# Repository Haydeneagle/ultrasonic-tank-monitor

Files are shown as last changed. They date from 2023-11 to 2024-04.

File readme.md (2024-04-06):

# Ultrasonic Tank Monitor using ESP32-C3

## Overview

This project is a wireless water tank monitoring solution, based on the ESP32-C3 microcontroller. 

To measure the water level, the AJ-SR04M waterproof ultrasonic sensor is used, measuring the height of the water level. This measured height value combined with the tank diameter and height of the sensor above the full water mark allows for the volume of the tank to be calculated.

Currently, the data is transmitted over Wi-Fi using the MQTT protocol to communicate with a Mosquitto broker linked to Home Assistant, allowing for the data to be easily visualized and used in home automations. In the near future I will likely replace Wi-Fi with LoRa however currently I do not have a gateway, so provided Wi-Fi signal is adequate, it works well.

A custom PCB has been created to interface the ESP32-C3 with a number of ports, while also optimizing for low power usage in deep sleep with a 70uA quiescent current and 30+ day battery life. The board is powered by a single Li-ion 4.2V 18650 cell and supports charging by both 5V USB, and via the solar input.

|Ready for installation|Installed|
|:-:|:-:|
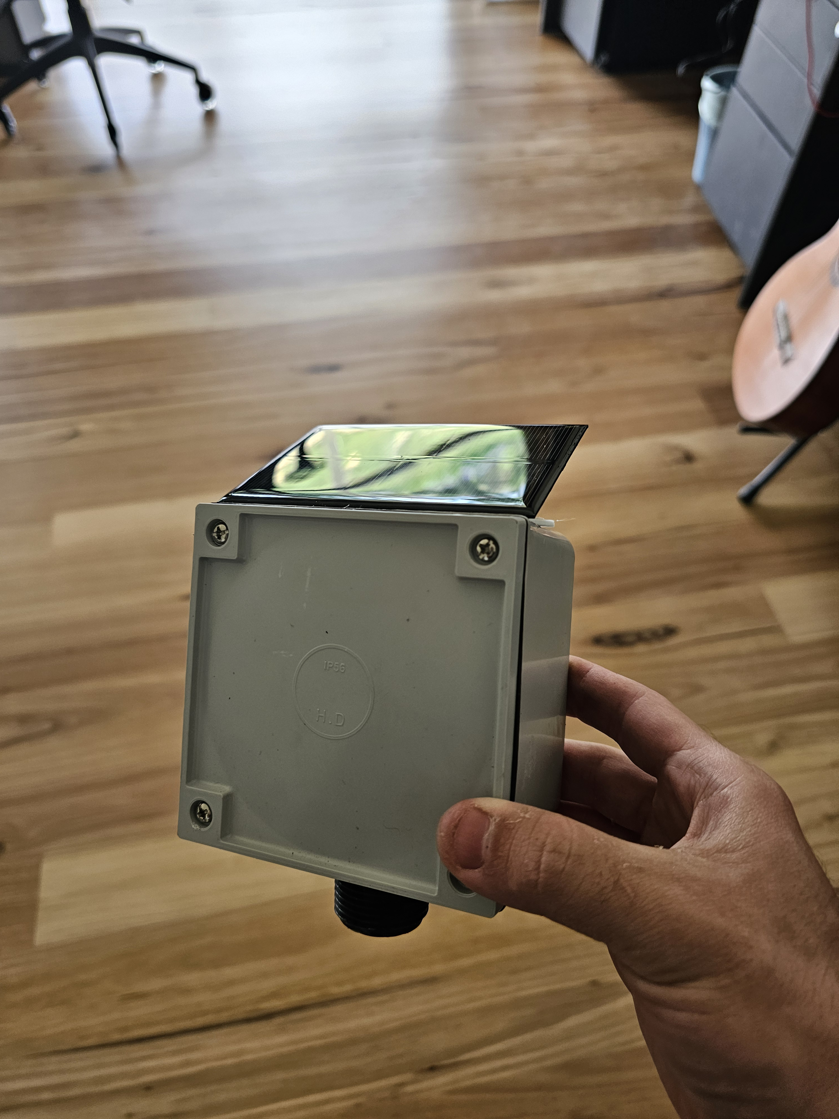
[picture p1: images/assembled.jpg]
A picture of a unit fully assembled ready to be installed
 | A picture of a unit installed into a tank

## Features
* WiFiManager for simple first time Wi-Fi setup
* OTA updating
* Simple installation and construction
* Low 70uA quiescent current allowing for 30+ day battery life
* Dual USB/Solar charge input
* +- 1 CM accuracy in measurement
* Simple communications for integration with MQTT for various uses
* Built in battery protection
* Optional support for water temperature sensor
* Access to full ESP32-C3 IO through header pins

## Software
The project is built on the Arduino framework for ESP32 and all code is visible in this repo. It is solely designed to integrate with the Mosquitto broker hosted on a Home Assistant server. While this functionalty is its primary purpose, there is no reason it cannot publish the data to any other MQTT broker for any other purpose.

When used with Home Assistant, the device will publish Discovery messages to automatically be found by Home Assistant and be added as an Entity. This means no direct configuration is required on Home Assistant, and the entity can be used immediately in Automations or visualizations.

The WifiManager library is used to handle connection to a Wi-Fi network. If no credentials are saved, it will broadcast an access point for a client to connect to and configure the chosen network directly. Once a network has been saved, the device will automatically connect seamlessly.

The PubSubClient library handles all required MQTT communications, allowing easy connection to a broker and both subscribing and publishing messages.

To collect the measurement, the NewPing library is utilized to interface with the ultrasonic sensor. This library samples the sensor 10 times and finds the median value to remove most of the erronous data. The value is then stored.

It is then used to compute the volume of water remaining using the given total volume and area numbers. These results are formatted as a JSON doc, serialized, and published to the MQTT topic specified in the config.

The flowchart below shows a high level overview of a typical sequence of events. This does not include all possible events, however does give an idea for the two major paths, of whether the device publishes once and enters deep sleep, or whether the OTA flag is set and it enters a continual loop waiting for OTA updates.
A flow chart showing the general path in software

## Hardware
The entire PCB project can be found in the Altium folder in this repo. This includes source files for modification, but also prezipped Gerbers for manufacturing. To manufacture this board you can submit these to a website such as JLCPCB (who I use) or PCBWay, both of which who are very cheap suppliers. The components were purchased from LCSC I opted to hand solder the entire PCB, however in future I would order a stencil to apply paste and use a reflow oven as it was tedious and led to numerous errors.

#### *Revision 2 of the PCB is underway, and I would advise against attempting to produce Revision 1.*

Rev 2 is focused on fixing a number of issues with the original including:
* Correcting USB pair connections (were reversed) 
* Solar input can power circuit directly (was preventing battery charger IC from finishing charge)
* Correct board shape to fit into 76x76 enclosure
* Possibly switching to SMPS to maximize battery usage

### Hardware Specifications
* Solar input: 4.5-6V
* Battery type: Lithium-Ion 18650 4.2V

### Primary PCB Components
The primary ICs/modules used are
* ESP32-C3-WROOM-02-N4
* AP7361C-33E-13 1A 3.3V LDO
* TP4056 Lithium battery charger IC
* SKCL3130ME Battery protection IC
* TPS2116DRLR Power switch for peripherials

### Shopping List
I have listed below the items needed to recreate this project along with estimated associated costing in $AUD and including shipping. Obviously this can vary a lot so use it as an estimate.

1. Fully assembled ESP32-C3 custom PCB $20 (hand soldered by me)
2. Li-ion 4.2V 18650 cell (I have used Samsung INR18650-25R harvested out of a powertool battery but any will work) $3
3. [AJ-SR04M waterproof ultrasonic sensor](https://www.aliexpress.com/item/4001116678728.html?spm=a2g0o.order_list.order_list_main.5.41e31802lgvw9L) $6
4. [Adaptable Box 108mm x 108mm x 76mm](https://www.sparkydirect.com.au/p/NLS-30092-Adaptable-Box-108mm-x-108mm-x-76mm) $9
5. [1" BSP Thread Pipe Nipple](https://www.bunnings.com.au/philmac-1-bsp-thread-pipe-nipple_p4813780) $3
6. [5V 250mA Solar Panel 69x110mm](https://www.aliexpress.com/item/32906698984.html?spm=a2g0o.order_list.order_list_main.5.4acf1802ziiZYF) $3
7. [Clear silicone sealant](https://www.bunnings.com.au/parfix-300g-clear-all-purpose-silicone_p1232674)
8. [DS18B20 stainless Steel temperature sensor](https://www.aliexpress.com/item/4000068914916.html?spm=a2g0o.order_list.order_list_main.11.527418024KgMyr) $3

In addition to these parts, you will need a 5mm drill bit and holesaw for the solar input hole, and a 32mm holesaw for the nipple hole in the bottom of the enclosure. Clear silicone will then need to be used to seal up and holes onces fully assembled.

## Setup
All necessary software configuration takes place in the config.h and secret.h files. In future this will be via a web based page to facilitate easy modification once installed, however currently it is hard coded via the firmware. 
1. First, you will need to configure the specific tank measurements to suit your tank, this includes the total volume, diameter and the height the ultrasonic sensor is from the full water level (might be easier to update once installation is complete). 
2. The second configuration is the name and MQTT broker information to allow it to communicate successfully.
3. secret.h must be modified to include the credentials information for MQTT and the OTA login page.
4. On initial startup of the board, the device will broadcast a Wi-Fi hotspot for you to connect to. Upon connecting, you need to browse to 192.168.4.1 on your connected device. Here you will see the WiFiManager interface. Select your SSID and input the password and press save. The device will reboot and save the credentials for future use. 
5. The device should now connect successfully and publish its first measurement.
6. To enter OTA mode, you will need to publish the message "on" to the topic specified in otaTopic. Ensure this message is set to retained. On next wakeup, the device will begin transmitting rapidly while also hosting the OTA update page (and in future the configuration page)
7. To exit OTA mode, publish the retained message "off" and the device should enter deep sleep.

## TO-DO
* PCB Revision 2
* Web based configuration page
* Flash storage of configuration variables
* Smoothing function
* LoRa integration

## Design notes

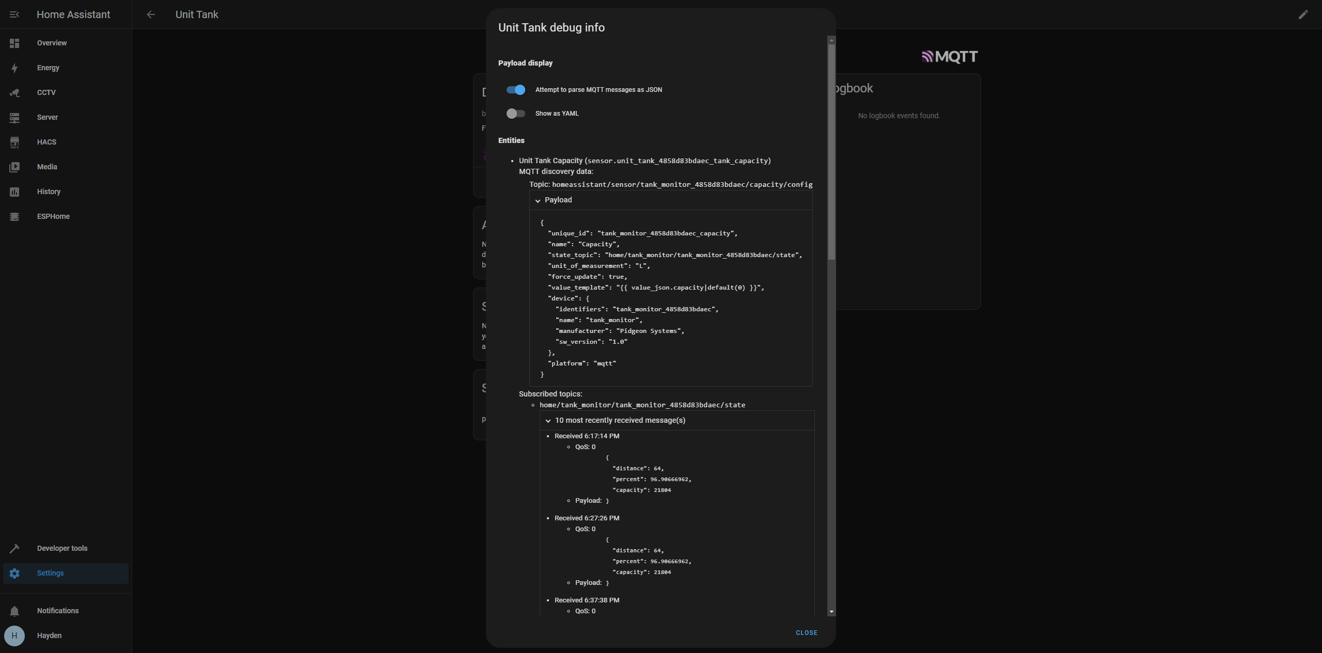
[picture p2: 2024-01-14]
images/Demo/MQTT payloads.png

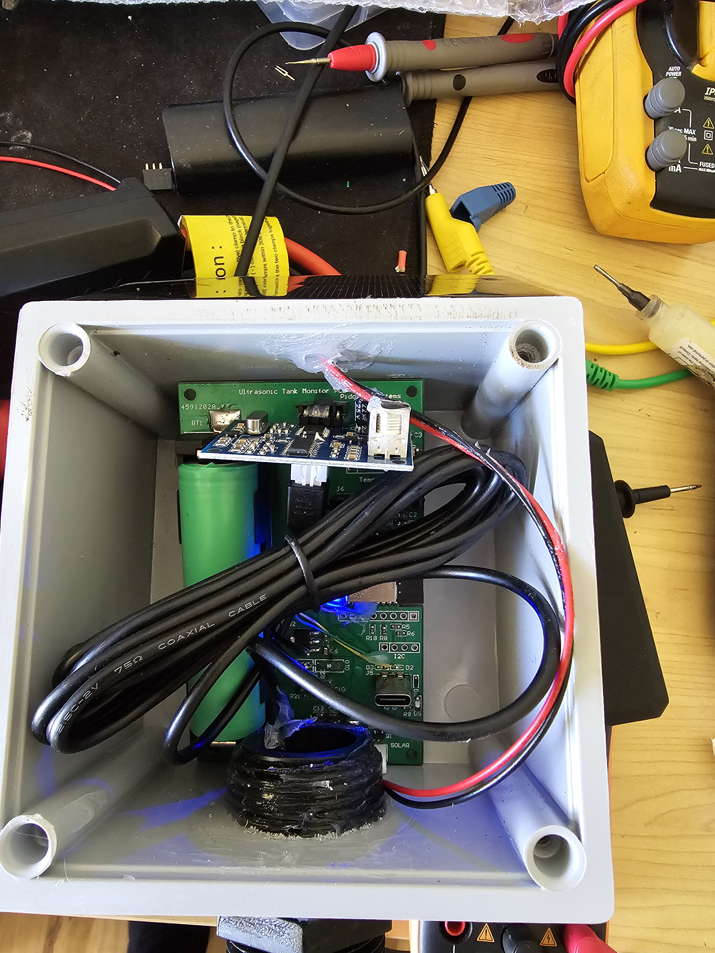
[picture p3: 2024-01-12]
images/inside_open.jpg

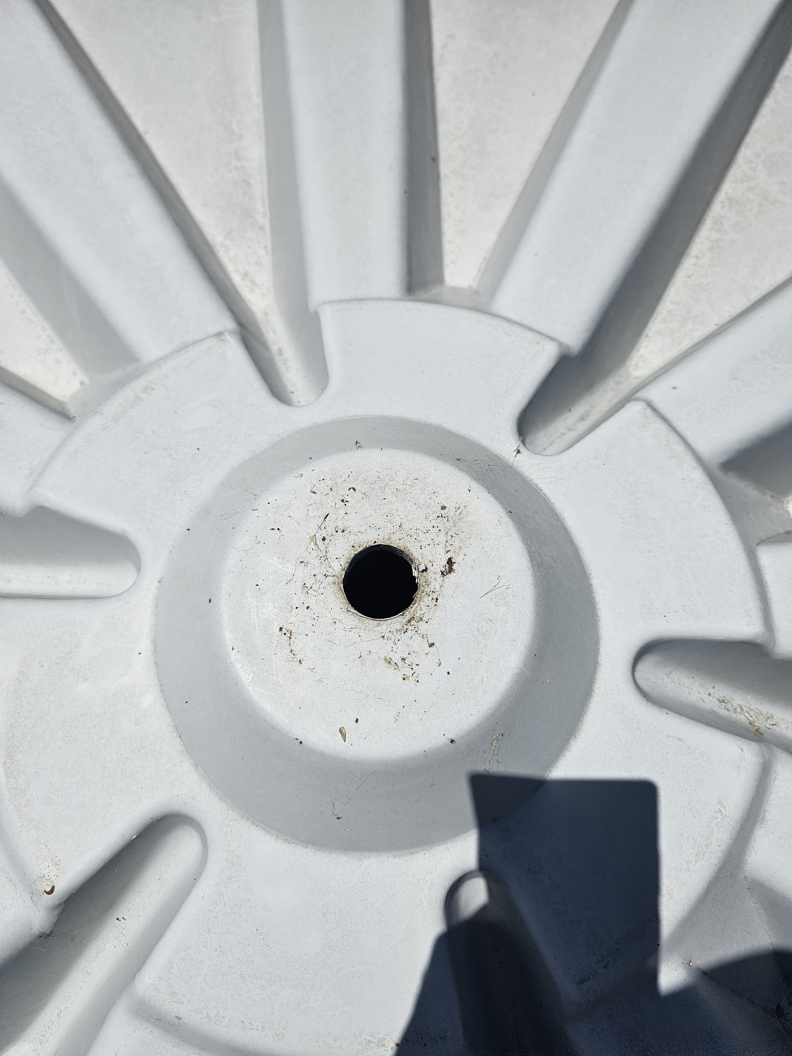
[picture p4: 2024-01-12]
images/tank_hole.jpg

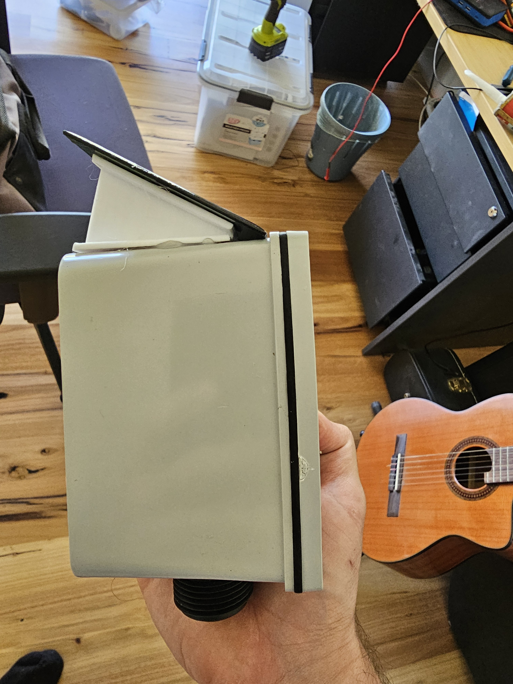
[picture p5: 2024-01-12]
images/side view.jpg

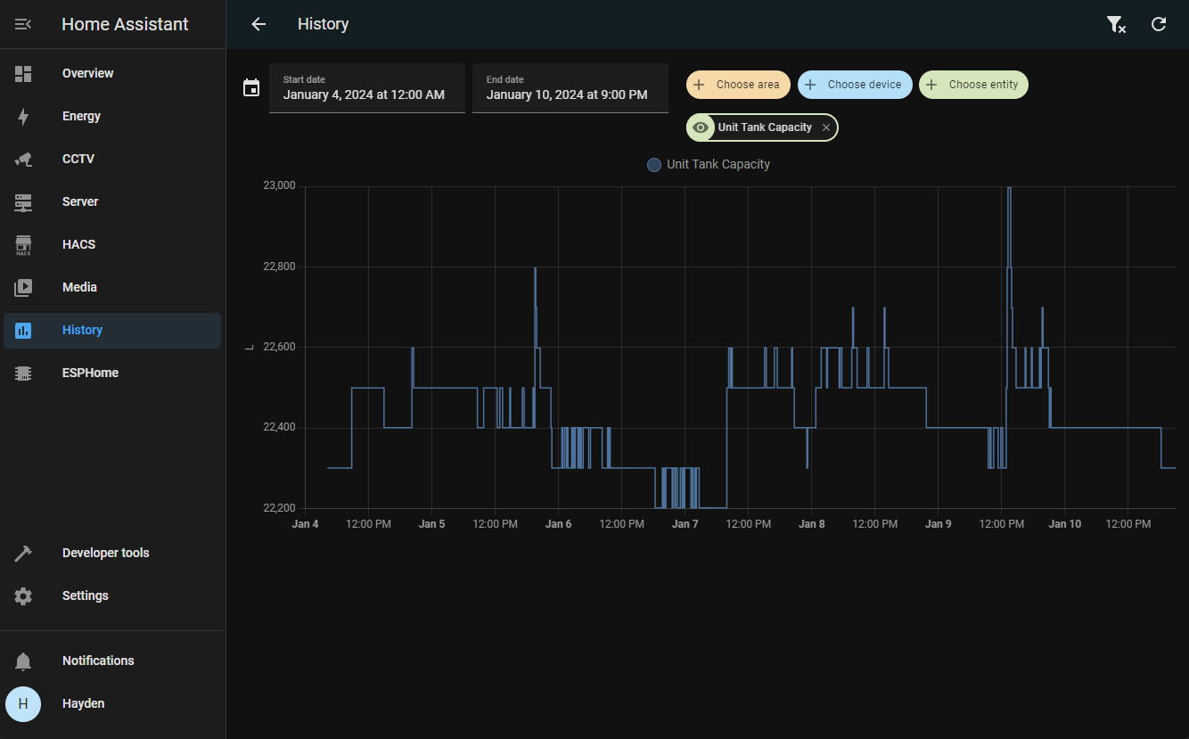
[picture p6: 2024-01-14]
images/Demo/HA graph.png

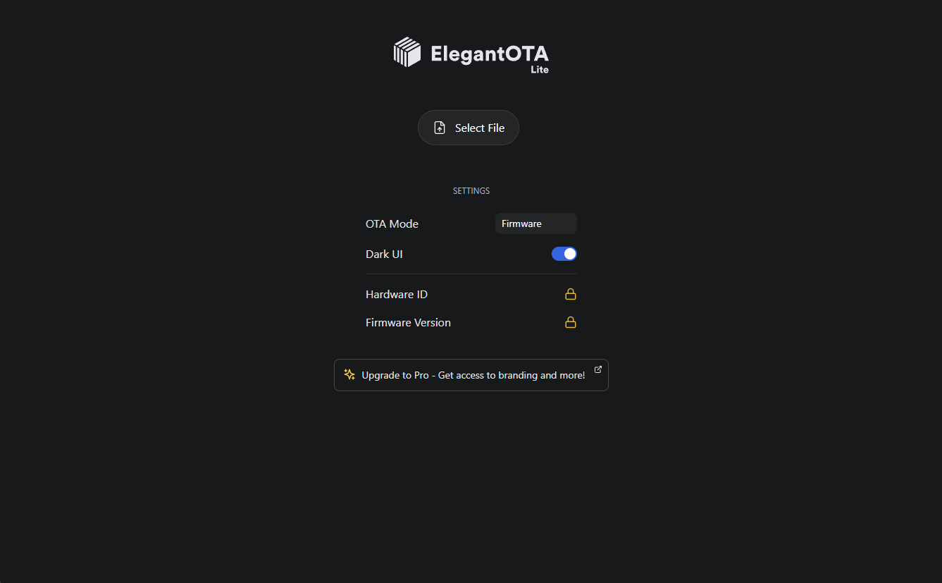
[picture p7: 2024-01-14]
images/Demo/ElegantOTA.png

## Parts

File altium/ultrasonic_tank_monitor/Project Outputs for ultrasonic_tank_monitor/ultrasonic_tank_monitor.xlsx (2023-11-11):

Comment | Description | Designator | Footprint | LibRef | Quantity
TP4056 |  |  | SOP-8_L4.9-W3.9-P1.27-LS6.0-TL-EP | TP4056 | 1
BH-18650-B1BA002 | 18650 SMD battery holder | BT1 | BATTERY-SMD_18650-1S-L77.1-W20.7-1 | 18650 SMD battery holder | 1 | LCSC Part Number | Manufacture Part Number | Manufacturer | Package | Customer # | Description | RoHS | Order Qty. | Min\Mult Order Qty. | Unit Price | Order Price | Product Link
10 µF | CAP CER 10UF 10V X5R 0603 | C1, C9, C10 | CAP 0603_1608 | GRM188R61A106ME69D | 3 | C19702 | CL10A106KP8NNNC | Samsung Electro-Mechanics | 603 | C1,C9,C10 | 10V 10uF X5R Â±10% 0603 Multilayer Ceramic Capacitors MLCC - SMD/SMT ROHS | yes | 100 | 100 | 0.0089 | 0.89 | https://assets.lcsc.com/images/lcsc/96x96/20180914_Samsung-Electro-Mechanics-CL10A106KP8NNNC_C19702_front_10.jpg
0.1 µF | CAP CER 0.1UF 10V X7R 0603 | C2, C5 | CAP 0603_1608 | VJ0603Y104MXQCW1BC | 2 | C2687355 | FN18X104K500GBG | PSA(Prosperity Dielectrics) | 603 | C2,C5 | 50V 100nF 0603 Multilayer Ceramic Capacitors MLCC - SMD/SMT ROHS | yes | 100 | 100 | 0.0024 | 0.24 | https://assets.lcsc.com/images/lcsc/96x96/20230130_PSA-Prosperity-Dielectrics-FN18X104K500GBG_C2687355_front.jpg
1 µF | CAP CER 1UF 10V X7R 0603 | C3, C4, C8, C11, C12 | CAP 0603_1608 | LMK107B7105KAHT | 5 | C1592 | CL10A105KO8NNNC | Samsung Electro-Mechanics | 603 | C3,C4,C8,C11,C12 | 16V 1uF X5R Â±10% 0603 Multilayer Ceramic Capacitors MLCC - SMD/SMT ROHS | yes | 100 | 100 | 0.0051 | 0.51 | https://assets.lcsc.com/images/lcsc/96x96/20221227_Samsung-Electro-Mechanics-CL10A105KO8NNNC_C1592_front.jpg
4.7 µF | CAP CER 4.7UF 16V X7R 0603 | C6, C7 | CAP 0603_1608 | GRM188Z71C475KE21J | 2 | C7432770 | HGC0603R5226M100NTHJ | Chinocera | 603 | C6 | 10V 22uF X5R Â±20% 0603 Multilayer Ceramic Capacitors MLCC - SMD/SMT ROHS | yes | 50 | 50 | 0.0215 | 1.08 | https://assets.lcsc.com/images/lcsc/96x96/20230722_Chinocera-HGC0603R5226M100NTHJ_C7432770_front.jpg
VESD16C1-02V-G3-08 | ESD PROTECTION DIODE SOD-523 | D1, D2, D3 | SOD523F | VESD16C1-02V-G3-08 | 3 | C140782 | GRM188R60J476ME15D | Murata Electronics | 603 | C6 | 6.3V 47uF X5R Â±20% 0603 Multilayer Ceramic Capacitors MLCC - SMD/SMT ROHS | yes | 5 | 5 | 0.1036 | 0.52 | https://assets.lcsc.com/images/lcsc/96x96/20181019_Murata-Electronics-GRM188R60J476ME15D_C140782_front.jpg
Blue | LED BLUE 0805 SMD | D4 | LED 0805_2012 BLUE | 5973605607F | 1 | C1705 | CL10A475KP8NNNC | Samsung Electro-Mechanics | 603 | C6,C7 | 10V 4.7uF X5R Â±10% 0603 Multilayer Ceramic Capacitors MLCC - SMD/SMT ROHS | yes | 100 | 100 | 0.0084 | 0.84 | https://assets.lcsc.com/images/lcsc/96x96/20221227_Samsung-Electro-Mechanics-CL10A475KP8NNNC_C1705_front.jpg
Red | LED RED 0805 SMD | D5, D7 | LED 0805_2012 RED | 5990110007F | 2 | C2836396 | SS34-MS | MSKSEMI | SMA(DO-214AC) | D1,D2,D3 | 40V 3A 550mV@3A SMA(DO-214AC) Schottky Barrier Diodes (SBD) ROHS | yes | 20 | 20 | 0.0345 | 0.69 | https://assets.lcsc.com/images/lcsc/96x96/20230120_MSKSEMI-SS34-MS_C2836396_front.jpg
SS34-HF | DIODE SCHOTTKY 40V 3A DO214AC | D6, D9, D10 | DO214AC SMA | SS34-HF | 3 | C502545 | ESD5Z3V3 | MDDï¼ˆMicrodiode Electronicsï¼‰ | SOD-523 | D1,D2,D3 | 14V 5V 3.3V SOD-523 TVS ROHS | yes | 50 | 50 | 0.0256 | 1.28 | https://assets.lcsc.com/images/lcsc/96x96/20230119_MDD-Microdiode-Electronics--ESD5Z3V3_C502545_front.jpg
Green | LED GREEN 0805 SMD | D8 | LED 0805_2012 GREEN | 5990181007F | 1 | C965817 | XL-2012UBC | XINGLIGHT | 805 | D4 | Colorless transparence -30â„ƒ~+85â„ƒ Positive post 460nm~469nm blue 120Â° 80mW 0805 Light Emitting Diodes (LED) ROHS | yes | 100 | 100 | 0.0103 | 1.03 | https://assets.lcsc.com/images/lcsc/96x96/20230131_XINGLIGHT-XL-2012UBC_C965817_front.jpg
Ultrasonic |  | J1 | HDR-TH_4P-P2.54-V-M | HDR-TH_4P-P2.54 | 1 | C965812 | XL-2012SURC | XINGLIGHT | 805 | D5,D7 | Colorless transparence -30â„ƒ~+85â„ƒ Positive post 617nm~621nm Red 120Â° 55mW 0805 Light Emitting Diodes (LED) ROHS | yes | 100 | 100 | 0.0081 | 0.81 | https://assets.lcsc.com/images/lcsc/96x96/20230131_XINGLIGHT-XL-2012SURC_C965812_front.jpg
UART |  | J2 | HDR-TH_4P-P2.54-V-M | HDR-TH_4P-P2.54 | 1 | C965815 | XL-2012UGC | XINGLIGHT | 805 | D8 | Colorless transparence 516nm~525nm -30â„ƒ~+85â„ƒ Positive post Emerald 120Â° 80mW 0805 Light Emitting Diodes (LED) ROHS | yes | 100 | 100 | 0.0079 | 0.79 | https://assets.lcsc.com/images/lcsc/96x96/20230131_XINGLIGHT-XL-2012UGC_C965815_front.jpg
B2B-PH-K-S | 2 Pin JST PH 2.0 Connector Straight | J3 | CONN-TH_B2B-PH-K-S | B2B-PH-K-S | 1 | C131337 | B2B-PH-K-S(LF)(SN) | JST Sales America | Plugin,P=2mm | J3 | 1x2P PH 1 2mm 2 Brass Plugin,P=2mm Wire To Board / Wire To Wire Connector ROHS | yes | 20 | 20 | 0.045 | 0.9 | https://assets.lcsc.com/images/lcsc/96x96/20230102_JST-Sales-America-B2B-PH-K-S-LF-SN_C131337_front.jpg
Temp |  | J4 | HDR-TH_4P-P2.54-V-M | HDR-TH_4P-P2.54 | 1 | C3151747 | TYPE-C 16PLC-H10.0 | SHOU HAN | Plugin | J5 | 5A 1 Vertical plug 16P Female -40â„ƒ~+85â„ƒ Type-C Plugin USB Connectors ROHS | yes | 5 | 5 | 0.3199 | 1.6 | https://assets.lcsc.com/images/lcsc/96x96/20230127_SHOU-HAN-TYPE-C-16PLC-H10-0_C3151747_front.jpg
TYPE-C 16PLC-H10.0 |  | J5 | TYPE-C-TH_16PLC-H10.0 | TYPE-C 16PLC-H10.0 | 1 | C173752 | S2B-PH-K-S(LF)(SN) | JST Sales America | Push-Pull,P=2mm | J9 | 1x2P PH 1 2mm 2 Brass Push-Pull,P=2mm Wire To Board / Wire To Wire Connector ROHS | yes | 20 | 20 | 0.0455 | 0.91 | https://assets.lcsc.com/images/lcsc/96x96/20230112_JST-Sales-America-S2B-PH-K-S-LF-SN_C173752_front.jpg
HDR-TH_8P-P2.54 |  | J6, J7 | HDR-TH_8P-P2.54-V-M | HDR-TH_8P-P2.54 | 2 | C5261052 | SI2301-ZE | HXY MOSFET | SOT-23(TO-236) | Q1 | 20V 2.3A 0.7W 126mÎ©@4.5V P Channel SOT-23(TO-236) MOSFETs ROHS | yes | 50 | 50 | 0.0185 | 0.93 | https://assets.lcsc.com/images/lcsc/96x96/20230126_HXY-MOSFET-SI2301-ZE_C5261052_front.jpg
I2C |  | J8 | HDR-TH_4P-P2.54-V-M | HDR-TH_4P-P2.54 | 1 | C103199 | RTT031002FTP | RALEC | 603 | R1,R8,R18,R23 | 100mW Thick Film Resistors Â±100ppm/â„ƒ Â±1% 10kÎ© 0603 Chip Resistor - Surface Mount ROHS | yes | 100 | 100 | 0.0016 | 0.16 | https://assets.lcsc.com/images/lcsc/96x96/20230102_RALEC-RTT031002FTP_C103199_front.jpg
S2B-PH-K-S | 2 Pin JST PH 2.0 Connector RA | J9 | CONN-TH_S2B-PH-K-S-LF-SN | S2B-PH-K-S | 1 | C136582 | RS-03000FT | FH (Guangdong Fenghua Advanced Tech) | 603 | R10 | 100mW Â±1% 0Î© 0603 Chip Resistor - Surface Mount ROHS | yes | 100 | 100 | 0.0013 | 0.13 | https://assets.lcsc.com/images/lcsc/96x96/20180914_FH--Guangdong-Fenghua-Advanced-Tech-RS-03000FT_C136582_front.jpg
SI2301-ZE | P-CHAN Mosfet SI2301 | Q1 | SOT-23-3_L2.9-W1.3-P1.90-LS2.4-BR | SI2301-ZE | 1 | C115420 | RS-03K1000FT | FH (Guangdong Fenghua Advanced Tech) | 603 | R11 | 100mW Â±100ppm/â„ƒ Â±1% 100Î© 0603 Chip Resistor - Surface Mount ROHS | yes | 100 | 100 | 0.0013 | 0.13 | https://assets.lcsc.com/images/lcsc/96x96/20230101_FH--Guangdong-Fenghua-Advanced-Tech-RS-03K1000FT_C115420_front.jpg
10 kOhms | RES SMD 10K OHM 5% 1/10W 0603 | R1, R8, R18, R23 | RES 0603_1608 | CRCW060310K0JNEB | 4 | C859933 | RL1206FR-7W0R4L | YAGEO | 1206 | R13 | 500mW Thick Film Resistors Â±300ppm/â„ƒ Â±1% 400mÎ© 1206 Chip Resistor - Surface Mount ROHS | yes | 20 | 20 | 0.031 | 0.62 | https://assets.lcsc.com/images/lcsc/96x96/20230630_YAGEO-RL1206FR-7W0R4L_C859933_front.jpg
5.1K | RES 5.1K OHM 5% 1/10W 0603 | R2, R3 | RES 0603_1608 | RMEF0603JT5K10 | 2 | C294654 | RS-03K2401FT | FH (Guangdong Fenghua Advanced Tech) | 603 | R16 | 100mW Â±100ppm/â„ƒ Â±1% 2.4kÎ© 0603 Chip Resistor - Surface Mount ROHS | yes | 100 | 100 | 0.0013 | 0.13 | https://assets.lcsc.com/images/lcsc/96x96/20180928_FH--Guangdong-Fenghua-Advanced-Tech-RS-03K2401FT_C294654_front.jpg
1 kOhms | RES 1K OHM 5% 1/10W 0603, RES 1K OHM 5% 1/4W 0603 | R4, R14, R15 | RES 0603_1608 | WR06X102 JTL, SR0603JR-7T1KL | 3 | C2907044 | FRC0603F5101TS | FOJAN | 603 | R2,R3 | 100mW Thick Film Resistors Â±100ppm/â„ƒ Â±1% 5.1kÎ© 0603 Chip Resistor - Surface Mount ROHS | yes | 100 | 100 | 0.0015 | 0.15 | https://assets.lcsc.com/images/lcsc/96x96/20230121_FOJAN-FRC0603F5101TS_C2907044_front.jpg
4.7 kOhms | RES 4.7K OHM 1% 1/10W 0603 | R5, R6, R7 | RES 0603_1608 | WR06X4701FTL | 3 | C304740 | RS-03K3601FT | FH (Guangdong Fenghua Advanced Tech) | 603 | R21 | 100mW Â±100ppm/â„ƒ Â±1% 3.6kÎ© 0603 Chip Resistor - Surface Mount ROHS | yes | 100 | 100 | 0.0013 | 0.13 | https://assets.lcsc.com/images/lcsc/96x96/20181129_FH--Guangdong-Fenghua-Advanced-Tech-RS-03K3601FT_C304740_front.jpg
2 kOhms | RES 2K OHM 5% 1/10W 0603 | R9 | RES 0603_1608 | RC0603JR-102KL | 1 | C310277 | RS-03K3302FT | FH (Guangdong Fenghua Advanced Tech) | 603 | R22 | 100mW Â±100ppm/â„ƒ Â±1% 33kÎ© 0603 Chip Resistor - Surface Mount ROHS | yes | 100 | 100 | 0.0013 | 0.13 | https://assets.lcsc.com/images/lcsc/96x96/20180929_FH--Guangdong-Fenghua-Advanced-Tech-RS-03K3302FT_C310277_front.jpg
0 Ohms | RES SMD 0.0 JUMPER 1/10W 0603 | R10 | RES 0603_1608 | WR06X000 PTL | 1 | C21190 | 0603WAF1001T5E | UNI-ROYAL(Uniroyal Elec) | 603 | R4,R14,R15 | 100mW Thick Film Resistors Â±100ppm/â„ƒ Â±1% 1kÎ© 0603 Chip Resistor - Surface Mount ROHS | yes | 100 | 100 | 0.001 | 0.1 | https://assets.lcsc.com/images/lcsc/96x96/20221229_UNI-ROYAL-Uniroyal-Elec-0603WAF1001T5E_C21190_front.jpg
100 Ohms | RES 100 OHM 5% 1/10W 0603 | R11 | RES 0603_1608 | WR06X101 JTL | 1 | C116693 | RS-03K4701FT | FH (Guangdong Fenghua Advanced Tech) | 603 | R5,R6,R7 | 100mW Â±100ppm/â„ƒ Â±1% 4.7kÎ© 0603 Chip Resistor - Surface Mount ROHS | yes | 100 | 100 | 0.0013 | 0.13 | https://assets.lcsc.com/images/lcsc/96x96/20230101_FH--Guangdong-Fenghua-Advanced-Tech-RS-03K4701FT_C116693_front.jpg
0 Ohms | RES SMD 0 OHM 3/4W 1206 WIDE | R12, R17 | RES 1206_3216 | RCL06120000Z0EA | 2 | C115336 | RS-03K2001FT | FH (Guangdong Fenghua Advanced Tech) | 603 | R9 | 100mW Â±100ppm/â„ƒ Â±1% 2kÎ© 0603 Chip Resistor - Surface Mount ROHS | yes | 100 | 100 | 0.0013 | 0.13 | https://assets.lcsc.com/images/lcsc/96x96/20230102_FH--Guangdong-Fenghua-Advanced-Tech-RS-03K2001FT_C115336_front.jpg
200 mOhms | RES 0.2 OHM 1% 1/2W 1206 | R13 | RES 1206_3216 | PT1206FR-7W0R2L | 1 | C7419910 | ZX-QC-LT43216 | Megastar | SMD | SW1,SW2 | NO 50mA 100MÎ© 100000 Times 12V 160gf@Â±50gf Brick nogging SPST SMD Tactile Switches ROHS | yes | 10 | 10 | 0.0376 | 0.38 | https://assets.lcsc.com/images/lcsc/96x96/20230630_Megastar-ZX-QC-LT43216_C7419910_front.jpg
2.4 kOhms | RES 2.4K OHM 5% 0.3W 0603 | R16 | RES 0603_1608 | SDR03EZPJ242 | 1 | C2934560 | ESP32-C3-WROOM-02-N4 | Espressif Systems | VFQFN-32-EP | U1 | 20.5dBm ESP32-C3 2.4GHz VFQFN-32-EP WiFi Modules ROHS | yes | 5 | 1 | 4.3976 | 21.99 | https://assets.lcsc.com/images/lcsc/96x96/20230121_Espressif-Systems-ESP32-C3-WROOM-02-N4_C2934560_front.jpg
3.6 kOhms | RES SMD 3.6K OHM 1% 1/10W 0603 | R21 | RES 0603_1608 | RT0603FRE073K6L | 1 | C500795 | AP7361C-33E-13 | Diodes Incorporated | SOT-223 | U2 | 1A null 3.3V positive 6V SOT-223 Linear Voltage Regulators (LDO) ROHS | yes | 10 | 5 | 0.2372 | 2.37 | https://assets.lcsc.com/images/lcsc/96x96/20230107_Diodes-Incorporated-AP7361C-33E-13_C500795_front.jpg
33 kOhms | RES 33K OHM 1% 1/10W 0603 | R22 | RES 0603_1608 | WR06X3302FTL | 1 | C2941741 | SKCL3130ME | Shikues | SOT-23-5 | U3 | -0.3V~6V é”‚ç¦»å /Polymer SOT-23-5 Battery Management ICs ROHS | yes | 5 | 5 | 0.1603 | 0.8 | https://assets.lcsc.com/images/lcsc/96x96/20230729_Shikues-SKCL3130ME_C2941741_front.jpg
TS-1185-B-A-B-A | Tactile Switch SMD 4x3x2 50mA | SW1, SW2 | SW-SMD_L4.0-W3.0-LS5.0 | TS-1185-B-A-B-A | 2 | C3236241 | AP22818AKBWT-7 | Diodes Incorporated | SOT-23-5 | U4 | 2.7V~5.5V 75mÎ© 2A SOT-23-5 Power Distribution Switches ROHS | yes | 10 | 5 | 0.1323 | 1.32 | https://assets.lcsc.com/images/lcsc/96x96/20230626_Diodes-Incorporated-AP22818AKBWT-7_C3236241_front.jpg
ESP32-C3 |  | U1 | BULETM-SMD_ESPRESSIF_ESP32-C3-WROOM-02-N4-4MB | ESP32-C3-WROOM-02-N4(4MB) | 1 | C3235557 | TPS2116DRLR | Texas Instruments | SOT-583 | U5 | 1.6V~5.5V 42mÎ© 2.5A SOT-583 Power Distribution Switches ROHS | yes | 10 | 1 | 0.7535 | 7.54 | -
AP7361C-33Y5-13 | 3V3 LDO low drop out and low Iq | U2 | SOT-223_L6.5-W3.5-P2.30-LS7.0-BR | AP7361C-33Y5-13 | 1 | C965848 | XL-2012RGBC | XINGLIGHT | 805 |  | Colorless transparence -30â„ƒ~+85â„ƒ Positive post RGB 120Â° 0805 Light Emitting Diodes (LED) ROHS | yes | 20 | 20 | 0.0529 | 1.06 | https://assets.lcsc.com/images/lcsc/96x96/20230131_XINGLIGHT-XL-2012RGBC_C965848_front.jpg
SKCL3130ME | 1 cell battery protection IC Li-ion OC OV UV SOT 23-5 | U3 | SOT-23-5_L2.9-W1.6-P0.95-LS2.8-BR | SKCL3130ME | 1 | C7473158 | TP4056-MS | MSKSEMI | SOP-8-EP |  | SOP-8-EP Battery Management ICs ROHS | yes | 10 | 10 | 0.091 | 0.91 | https://assets.lcsc.com/images/lcsc/96x96/20230828_MSKSEMI-TP4056-MS_C7473158_front.jpg
AP22818AKBWT-7 | High active 2A load distribution switch | U4 | SOT-23-5_L2.9-W1.6-P0.95-LS2.8-BR | AP22818AKBWT-7 | 1
TPS2116DRLR | 2 IN 1 OUT Power MUX 1.6-5.5V 2.5A low-IQ | U5 | SOT-583-8_L2.1-W1.6-P0.50-LS1.6-BL | TPS2116DRLR | 1

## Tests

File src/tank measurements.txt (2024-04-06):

UNIT
const int tankAdjust = 57; //distance from the bottom of the ultrasonic tranducer to the full water level mark
const int tankTotal = 22500;    //total water volume in L
const float tankDiameter = 3.56;

HOUSE
const int tankAdjust = 47; //distance from the bottom of the ultrasonic tranducer to the full water level mark
const int tankTotal = 27250;    //total water volume in L
const float tankDiameter = 3.65 ;

MAIN
const int tankAdjust = 51; //distance from the bottom of the ultrasonic tranducer to the full water level mark
const int tankTotal = 23500;    //total water volume in L
const float tankDiameter = 3.65 ;

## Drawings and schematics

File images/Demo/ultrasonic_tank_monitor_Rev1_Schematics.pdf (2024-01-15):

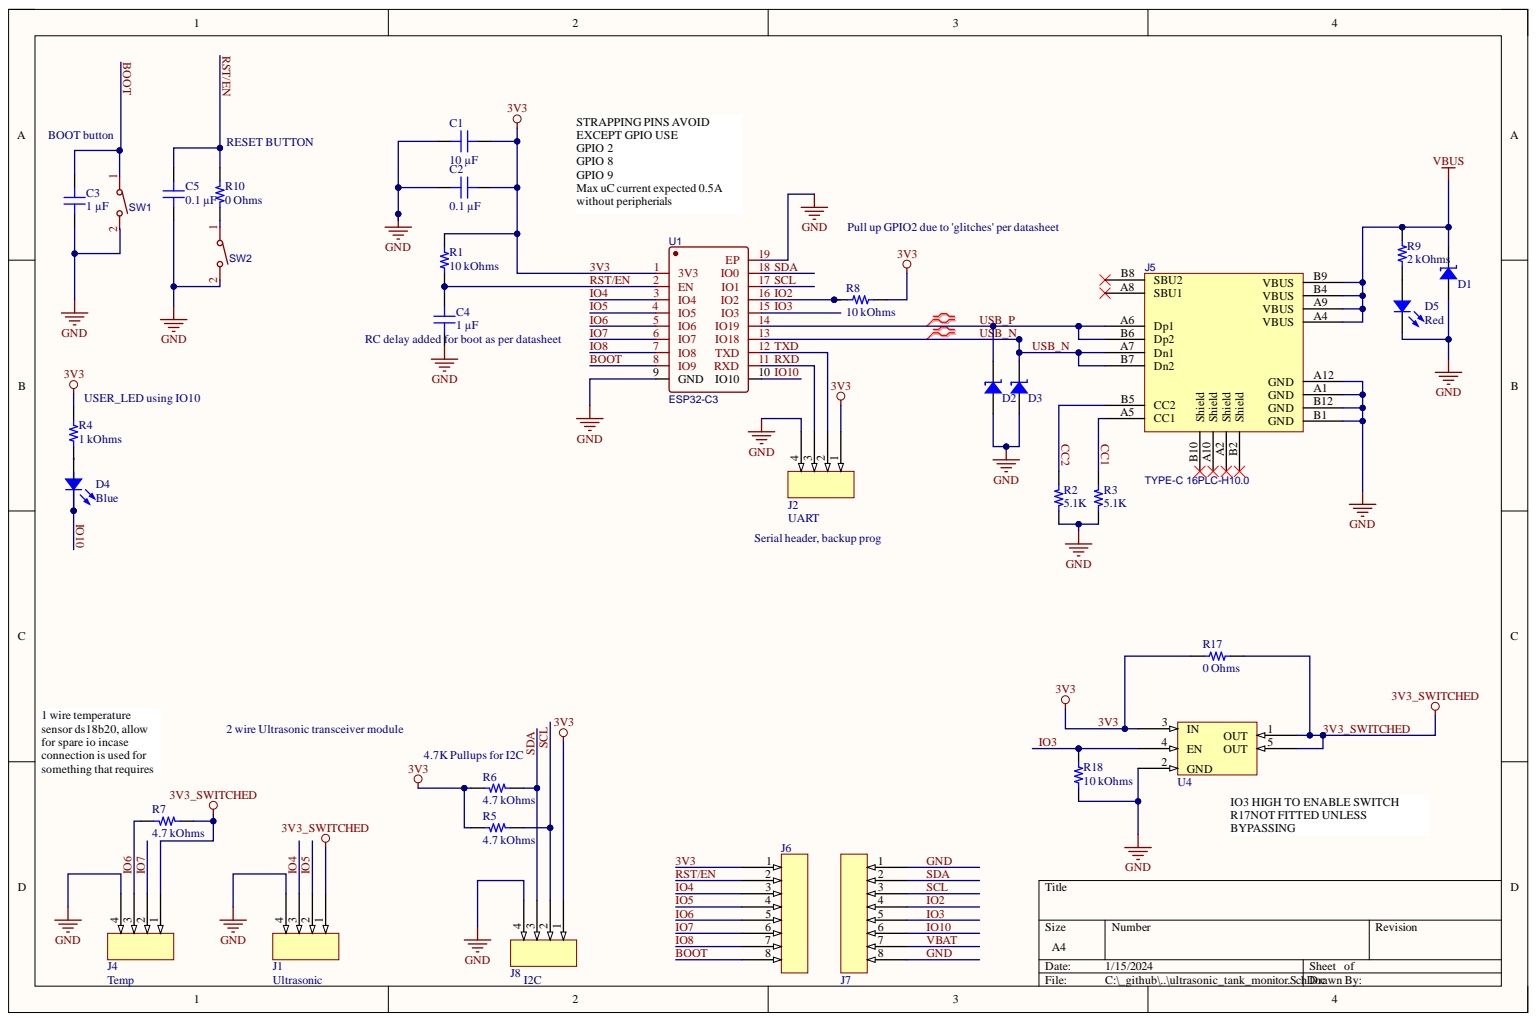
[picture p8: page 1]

STRAPPING PINS AVOID
EXCEPT GPIO USE
GPIO 2
GPIO 8
GPIO 9
Max uC current expected 0.5A
without peripherials

Pull up GPIO2 due to 'glitches' per datasheet

RC delay added for boot as per datasheet

Serial header, backup prog

1 wire temperature
sensor ds18b20, allow
for spare io incase
connection is used for
something that requires

2 wire Ultrasonic transceiver module

IO3 HIGH TO ENABLE SWITCH
R17NOT FITTED UNLESS
BYPASSING

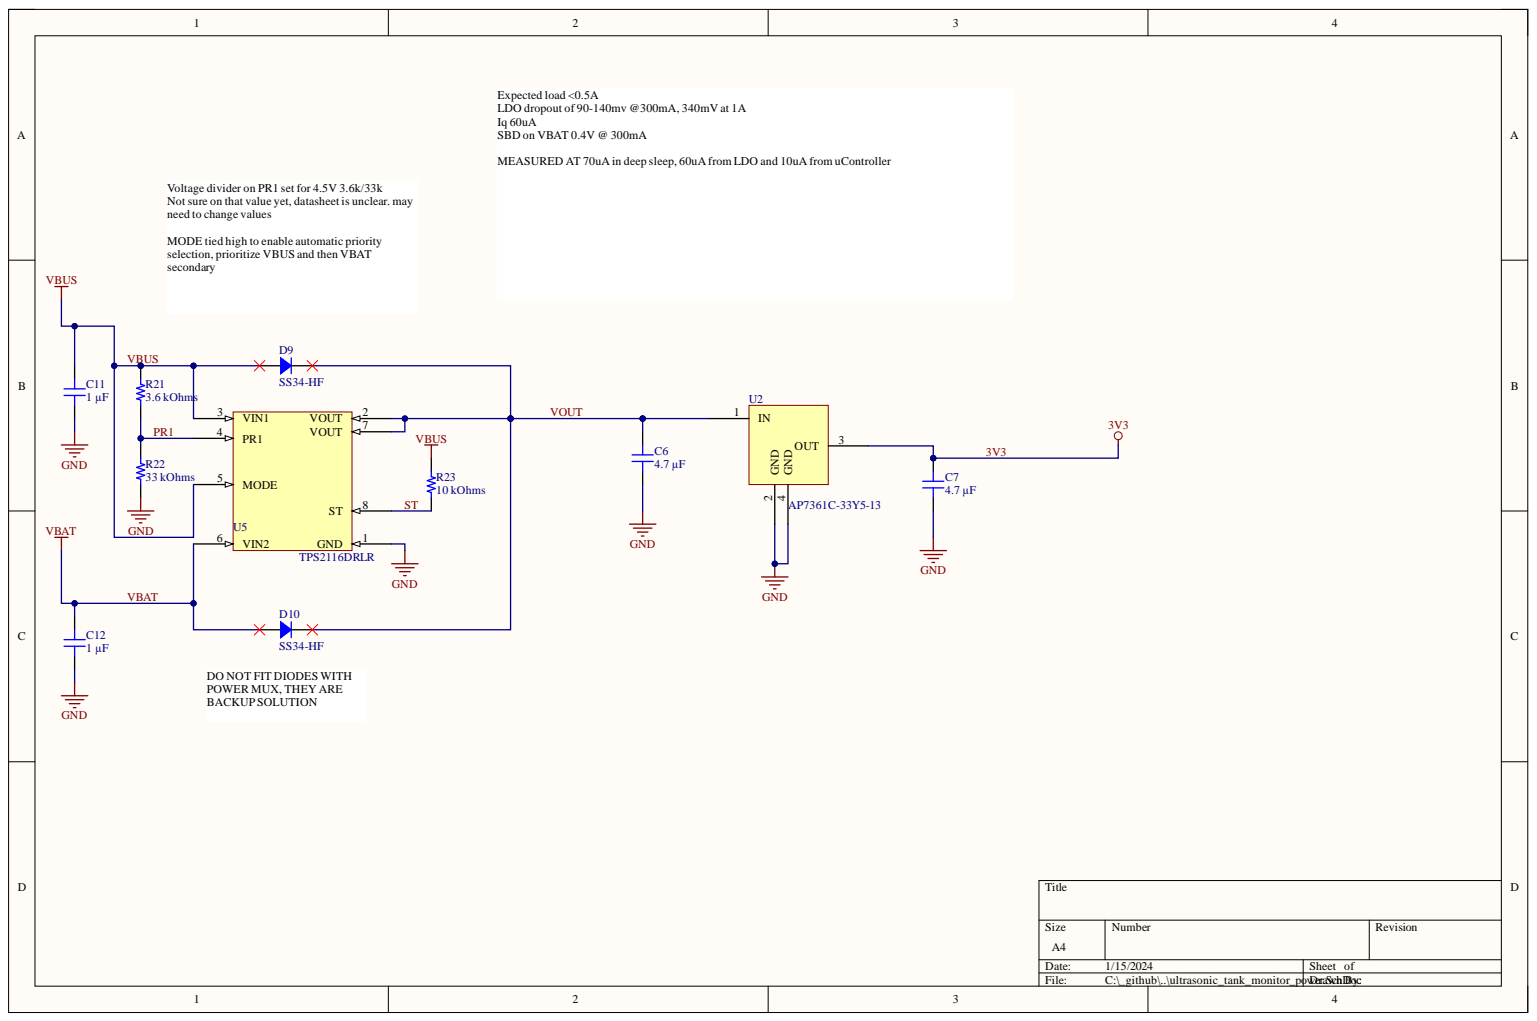
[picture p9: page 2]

VBU

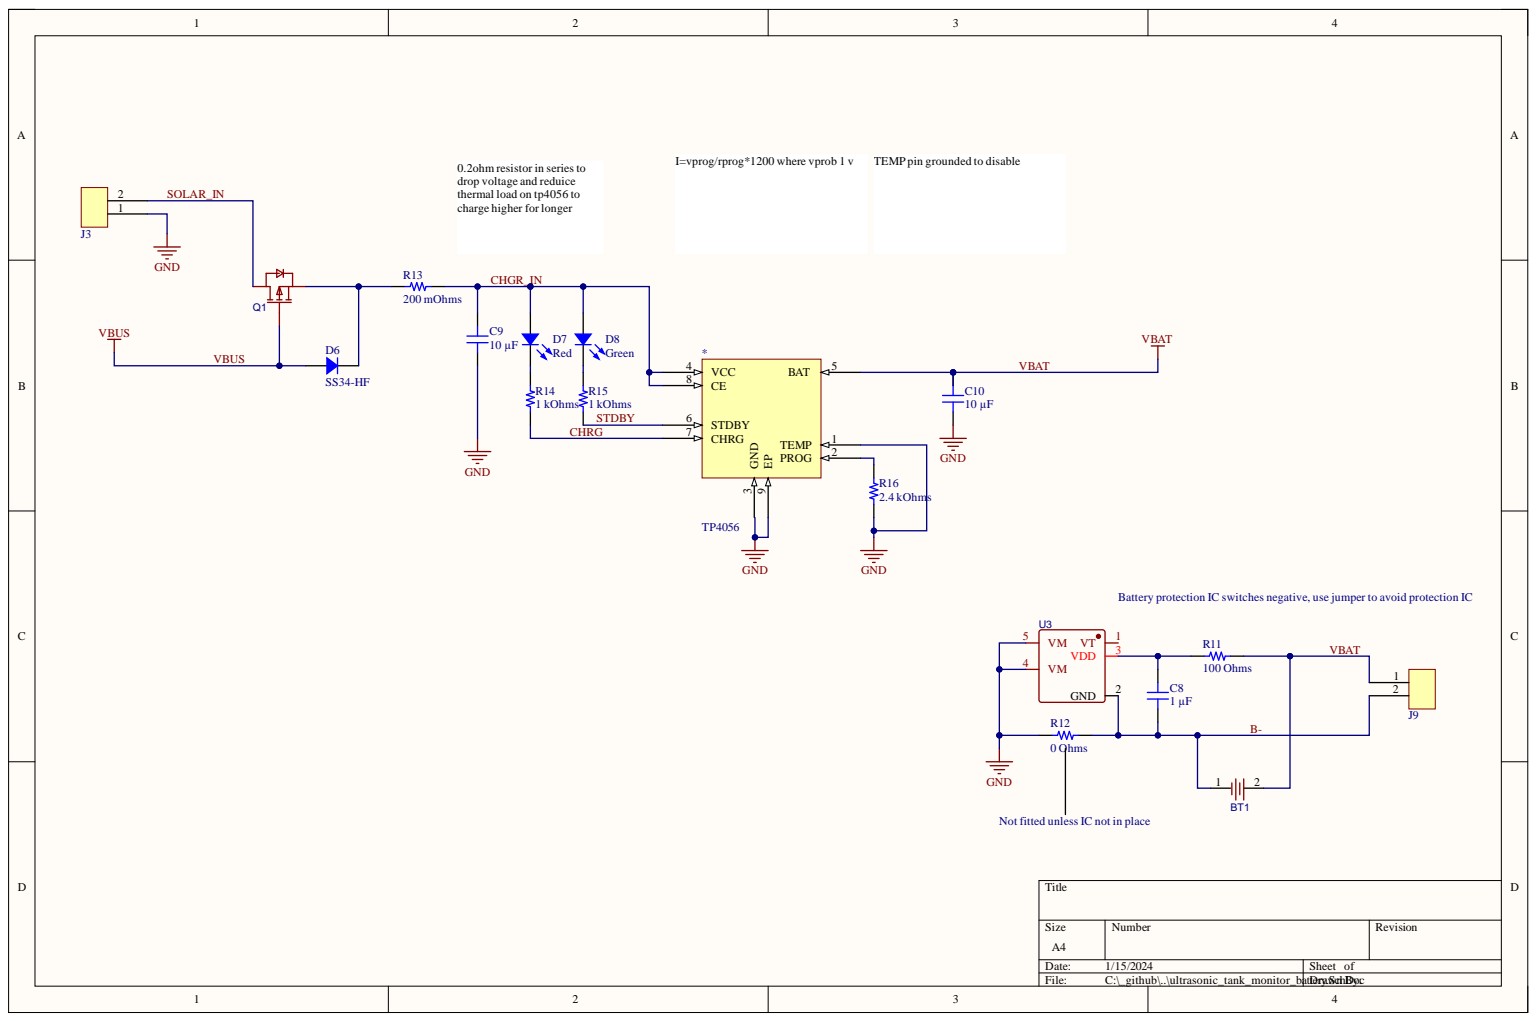
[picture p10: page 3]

0.2ohm resistor in series to
drop voltage and reduice
thermal load on tp4056 to
charge higher for longer

Battery protection IC switches negative, use jumper to avoid protection IC

Not fitted unless IC not in place

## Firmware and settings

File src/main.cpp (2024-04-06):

/*
this is the file 
*/

#include <WiFi.h>
#include <WiFiManager.h>
#include <AsyncTCP.h>
#include <ESPAsyncWebServer.h>
#include <ElegantOTA.h>
#include <PubSubClient.h>
#include <ArduinoJson.h>
#include <NewPing.h>  //for sonar modules

#include <config.h>
#include <secret.h>

RTC_DATA_ATTR int bootCount = 0; // set boot count so we know not to transmit on initial load

//construct objects, credentials stores in secret.h
WiFiManager wifiManager;
WiFiClient wifiClient;
PubSubClient client(wifiClient);

//pin definitions
#define periphPower 3 //pin must be set to high to switch 3v3 to peripherials
#define trigPin 5
#define echoPin 4
#define ledPin 10 //active low

//declare object of sonar
NewPing sonar[SONAR_NUM] = {   // Sensor object array.
NewPing(trigPin, echoPin, MAX_DISTANCE), // Each sensor's trigger pin, echo pin, and max distance to ping. 
};

AsyncWebServer server(80); //for ota updates

//create dynamic variables
int distance; //ultrasonic measurement distance
int tankVol; //tank maximum volume (L)
int capacity; //calculated water volume (L)
float percent; //percent remaining water

uint64_t lastPublish = esp_timer_get_time(); // used by publish
bool deepSleepDisable = 0;

void startOTA(){
  server.on("/", HTTP_GET, [](AsyncWebServerRequest *request) {
    request->send(200, "text/html", index_html);
  });

  ElegantOTA.setAuth(otaUser, otaPass);
  ElegantOTA.begin(&server);
  server.begin();
  Serial.println("HTTP server started");
}

void deepSleep() {
    Serial.println("entering Deep sleep mode");
    esp_sleep_enable_timer_wakeup(TIME_TO_SLEEP * uS_TO_S_FACTOR); //constants defined in config.h

    //Serial.flush(); // unused as was blocking code when no serial terminal connected...

    digitalWrite(ledPin, HIGH); //just ensure led is definitely off
    digitalWrite(periphPower, LOW); //ensure peripherials are off

    client.disconnect(); //disconnect from broker cleanly
    wifiClient.flush(); //flush wifi before sleep
    wifiClient.stop();

/*     while( client.state() != -1){  //commented to check if this blockign causes it to get stuck
    Serial.println(client.state());
    delay(10);
    } */
    esp_wifi_stop(); //force close wifi to be sure its off, drops from 1.6ma to 0.1ma
    esp_deep_sleep_start();
}

// Wifi Manager
void setupWifi() {
  Serial.println("Connecting to WiFi");

  String HOTSPOT = id;
  wifiManager.setSaveConnectTimeout(10); //set for redundancy due to constant connect errors. Might have been USB power supply rated, as no problemms on battery
  wifiManager.setConnectTimeout(15); 
  wifiManager.setConnectRetries(10); // we have plenty of battery life and this will rule out any issues with long range connections
  wifiManager.setConfigPortalTimeout(120);
  if (!wifiManager.autoConnect((const char * ) HOTSPOT.c_str())) {
    Serial.println("failed to connect and hit timeout, perform ESP.restart()");
    delay(100);
    ESP.restart();
  }
}

void sendMQTTPercentDiscoveryMsg() {
  String discoveryTopic = discTopic + "/percent/config";

  DynamicJsonDocument doc(2048);
  char buffer[2048];

  doc["uniq_id"] = id + "_percent";
  doc["name"] = "Percentage";
  doc["stat_t"]   = stateTopic;
  doc["unit_of_meas"] = "%";
  doc["frc_upd"] = true;
  doc["val_tpl"] = "{{ value_json.percent|default(0) }}";
  
  JsonObject dev = doc.createNestedObject("dev");
  dev["ids"] = id;
  dev["name"] = name;
  dev["mf"] = "Pidgeon Systems";
  dev["sw"] = "1.0";

  size_t n = serializeJson(doc, buffer);

  client.publish(discoveryTopic.c_str(), buffer, n);
}

void sendMQTTCapacityDiscoveryMsg() {
  String discoveryTopic = discTopic + "/capacity/config";

  DynamicJsonDocument doc(2048);
  char buffer[2048];

  doc["uniq_id"] = id + "_capacity";
  doc["name"] = "Capacity";
  doc["stat_t"]   = stateTopic;
  doc["unit_of_meas"] = "L";
  doc["frc_upd"] = true;
  doc["val_tpl"] = "{{ value_json.capacity|default(0) }}";
  
  JsonObject dev = doc.createNestedObject("dev");
  dev["ids"] = id;
  dev["name"] = name;
  dev["mf"] = "Pidgeon Systems";
  dev["sw"] = "1.0";

  size_t n = serializeJson(doc, buffer);

  client.publish(discoveryTopic.c_str(), buffer, n);
}

void sendMQTTDistanceDiscoveryMsg() {
  String discoveryTopic = discTopic + "/distance/config";

  DynamicJsonDocument doc(2048);
  char buffer[2048];

  doc["uniq_id"] = id + "_distance";
  doc["name"] = "Distance";
  doc["stat_t"]   = stateTopic;
  doc["unit_of_meas"] = "cm";
  doc["frc_upd"] = true;
  doc["val_tpl"] = "{{ value_json.distance|default(0) }}";
  
  JsonObject dev = doc.createNestedObject("dev");
  dev["ids"] = id;
  dev["name"] = name;
  dev["mf"] = "Pidgeon Systems";
  dev["sw"] = "1.0";

  size_t n = serializeJson(doc, buffer);

  client.publish(discoveryTopic.c_str(), buffer, n);
}

void callback(char* topic, byte* message, unsigned int length) {
  Serial.print("Message arrived on topic: ");
  Serial.print(topic);
  Serial.print(". Message: ");
  String messageTemp;
  
  for (int i = 0; i < length; i++) {
    Serial.print((char)message[i]);
    messageTemp += (char)message[i];
  }
  Serial.println();

  // checks message on /ota topic to see whether to enter OTA update mode, or return to deep sleep
  if (String(topic) == otaTopic.c_str()) {
    if (messageTemp == "on"){
      Serial.println("OTA mode on");
      deepSleepDisable = 1;
    }
    else { //(messageTemp == "off")
      Serial.println("OTA mode off");
      deepSleepDisable = 0;
    }
  }
}

void setupMQTT() {
  Serial.println("Configuring MQTT....");

  client.setServer(mqtt_server, 1883);
  client.setCallback(callback);
  client.setBufferSize(512);
  client.setKeepAlive(60);

    int counter = 0;
    while (!client.connected())
    {
      Serial.print("Attempting MQTT connection...");

      // Attempt to connect to mqtt
      if (client.connect(id.c_str(), mqttUser, mqttPassword))
      {
        Serial.println("connected");
        client.subscribe(otaTopic.c_str());
      }      
      else if (counter < 5) // delay and try again
      {
        counter += 1;    
        Serial.print("failed, rc=");
        Serial.print(client.state());
        Serial.println(" try again in 2 seconds");
        // Wait 2 seconds before retrying
        delay(2000);
      }
      else // go to sleep, taking longer than 10 sec
      {
        Serial.println("MQTT connection is taking too long, restart esp and try again later.");
        ESP.restart();
        //deepSleep();
      }
    }
}

void sendData(){ 
  StaticJsonDocument<128> doc;
  char buffer[128];

  //poll distance
  pinMode(periphPower, OUTPUT);
  digitalWrite(periphPower, HIGH);  //enable peripherial power
  delay(50);  //allow time for power up 50ms found to be sweet spot

  distance = sonar[0].convert_cm(sonar[0].ping_median(10)); //find median of 10 pings in cm
  delay(100);  //allow time for measurements before shutting power off

  //if distance is less than tankAdjust, return tank adjust to show 100%
  if (distance < tankAdjust) {
    distance = tankAdjust;
  }
  
  //calculate volume
  tankVol =  (((distance-tankAdjust)*10)*tankArea);
  capacity = tankTotalVol - tankVol;
  percent = ((float)capacity/(float)tankTotalVol)*100;

  // Print the distance on the Serial Monitor (Ctrl+Shift+M):
  Serial.print("tank Distance = ");
  Serial.print(distance);
  Serial.println(" cm");

  Serial.print("tank Litres = ");
  Serial.print(capacity);
  Serial.print(" litres, aka ");
  Serial.print(percent);
  Serial.println(" %");

  //set json values
  doc["distance"] = distance;
  doc["percent"] = percent;
  doc["capacity"] = capacity;
  size_t n = serializeJson(doc, buffer);

  digitalWrite(periphPower, LOW); // disable power to peripherials

  //send to mqtt
  bool published = client.publish(stateTopic.c_str(), buffer, n);
}


void flashLED(int onTime) {   //onTime representing time LED will remain on for
  digitalWrite(ledPin, LOW);  //low for en
  delay(onTime);
  digitalWrite(ledPin, HIGH);
}

void setup() {
  Serial.begin(115200);
  pinMode(ledPin, OUTPUT);
  digitalWrite(ledPin, HIGH); //active low, so disable

  setupWifi();
  
  setupMQTT();
  for (int i = 0; i < 10; i++) {
    client.loop();
    flashLED(200);
    delay(100);
  }

  if (deepSleepDisable == 1) {
    Serial.println("deepSleepDisable == 1");
    Serial.println("Starting OTA");
    startOTA();
    digitalWrite(ledPin, LOW); //led on for debugging, remove once working
  }
  else {
    Serial.println("deepsleepdisable == 0");

    sendMQTTPercentDiscoveryMsg();
    sendMQTTCapacityDiscoveryMsg();
    sendMQTTDistanceDiscoveryMsg();

    sendData();

    for (int i = 0; i < 5; i++) {//allow some time for data to transmit before jumping into deep sleep
    flashLED(300);
    delay(100);
    }
    deepSleep();
  }
}

//this code will only run when /ota topic is set to on, otherwise it will not enter loop()
void loop() {
  ElegantOTA.loop(); //has to be in loop to allow for reboot

  if (!wifiClient.connected()){
    Serial.println("Wifi Connection lost.. reconnecting");
    setupWifi();
  }

  if (!client.connected()) { //if lost mqtt connection, reconnect
    Serial.println("Connection lost.. reconnecting");
    setupMQTT();
  }

  client.loop();

  int TimeToPublish = 5000000; //5000000uS (5s)
  if ( (esp_timer_get_time() - lastPublish) >= TimeToPublish ) //transmit every 5s during active ota mode
    {
      sendData();// data for mqtt publish
      lastPublish = esp_timer_get_time(); // get next publish time
      Serial.println(lastPublish/1000000); //debugging to check timings
      Serial.println(client.state());
    }

  //if deepsleep or timer expired, restart/deepsleep
  if (deepSleepDisable == 0) {
    Serial.println("deepSleepDisable == 0");
    Serial.println("Entering deep sleep");
    deepSleep();
  }
  else if (esp_timer_get_time() >= 300000000){ //5 minutes restart to ensure no stuck loop
    ESP.restart();
  }
}

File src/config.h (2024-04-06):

/*
Config file for board including user changable variables
*/


#define uS_TO_S_FACTOR 1000000  /* Conversion factor for micro seconds to seconds */
#define TIME_TO_SLEEP  600       /* Time ESP32 will go to sleep (in seconds) */

#define SONAR_NUM 1      // Number of sensors.
#define MAX_DISTANCE 350 // Maximum distance (in cm) to ping.

//name, id and mqtt state topic
const String name = "tank_monitor"; //unused to maintain easy identification
const String id = name + "_" + String(ESP.getEfuseMac(), HEX); //primary ID, should be unique
const String topic = "home/tank_monitor/" + id;
const String otaTopic = topic + "/ota";
const String stateTopic = topic + "/state";
const String discTopic = "homeassistant/sensor/" + id;
const char* mqtt_server = "10.0.30.2";


//physical measurements ADJUST FOR INDIVIDUAL TANK DIMENSIONS
const int tankAdjust = 47; //distance from the bottom of the ultrasonic tranducer to the full water level mark
const int tankTotalVol = 27250;    //total water volume in L
const float tankDiameter = 3.65;
const float tankRadius = tankDiameter/2;
const float tankArea = M_PI * (tankRadius*tankRadius); //tank area m2

const char index_html[] PROGMEM = "<!DOCTYPE html><html lang=\"en\"><head><meta charset=\"UTF-8\"><meta name=\"viewport\" content=\"width=device-width,initial-scale=1\"><meta http-equiv=\"X-UA-Compatible\" content=\"ie=edge\"><title>Tank Monitor configuration</title><link rel=\"stylesheet\" href=\"style.css\"></head><body><script src=\"index.js\"></script><h1>Tank Monitor Configuration</h1><br><a href=\"/update\"><button>Update Firmware</button></a><h2>Device Settings</h2><p>Device Name:<br>ID:<br>Topic:<br>otaTopic:<br>StateTopic:<br>discTopic:<br>MQTT Server:<br></p><br><h2>Sleep Settings</h2><p>Time to sleep (s):</p><br><h2>Tank Settings</h2><p>Tank size (litres):<br>Distance to full water mark:<br>Tank Diameter:</p></body></html>"; // large char array, tested with 14k

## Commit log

2022-02-17 updated to working prototype
2023-10-15 begin pcb design
    [ultrasonic_tank_monitor.PcbDoc, ultrasonic_tank_monitor.PrjPcb, ultrasonic_tank_monitor.SchDoc]
2023-10-15 continue pcb design, add esp32-c3, add rst/boot buttons
    [ultrasonic_tank_monitor.PcbDoc, ultrasonic_tank_monitor.PrjPcb, ultrasonic_tank_monitor.SchDoc]
2023-10-16 continue pcb design, battery circuit complete, IO Close to complete, power supply remains.
    [ultrasonic_tank_monitor.PcbDoc, ultrasonic_tank_monitor.PrjPcb, ultrasonic_tank_monitor.SchDoc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]
2023-10-17 start layout for pcb
    [ultrasonic_tank_monitor.PcbDoc, ultrasonic_tank_monitor.PrjPcb, ultrasonic_tank_monitor.SchDoc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]
2023-10-17 continue placement
    [ultrasonic_tank_monitor.PcbDoc, ultrasonic_tank_monitor.SchDoc]
2023-10-18 finish routing
    [ultrasonic_tank_monitor - Board.step-1 Open CASCADE STEP translator 6.8 1.1.1.step-1.STL, ultrasonic_tank_monitor - C1.step-1 0603_cap.step-1.STL, ultrasonic_t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]
2023-10-18 add text, complete routing, generate gerbers + output job
    [ultrasonic_tank_monitor - Board.step-1 Open CASCADE STEP translator 6.8 1.1.1.step-1.STL, ultrasonic_tank_monitor - C1.step-1 0603_cap.step-1.STL, ultrasonic_t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]
2023-11-11 revert to custom firmware, begin code refactoring, add OTA functionality
    [ultrasonic_tank_monitor.PrjPcb, ultrasonic_tank_monitor.SchDoc, ultrasonic_tank_monitor.xlsx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]
2023-11-11 begin implementing mqtt deep sleep control for OTA
    [ultrasonic_tank_monitor.SchDoc]
2023-11-25 add ultrasonic functionality and fix mqtt topics
    [report.xlsx]
2023-11-28 fix discovery message to allow successful homeassistant discovery
    [config.h, main.cpp]
2023-11-29 update pcb to correct usb pair error and solar connector polarity
    [ultrasonic_tank_monitor.PcbDoc, ultrasonic_tank_monitor.SchDoc, ultrasonic_tank_monitor_battery.SchDoc]
2023-12-05 fix solar connector polarity, send data before enter deep sleep out of OTA, set config for unit tank
    [ultrasonic_tank_monitor.SchDoc, ultrasonic_tank_monitor_battery.SchDoc, ultrasonic_tank_monitor_power.SchDoc]
2023-12-06 being 2nd rev of pcb to fit enclosure and fix mistakes
    [ultrasonic_tank_monitor.PcbDoc]
2023-12-08 add tp5000 as new charge ic
    [Copy of ultrasonic_tank_monitor_battery_TP4056.SchDoc, ultrasonic_tank_monitor.PcbDoc, ultrasonic_tank_monitor.PrjPcb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]
2023-12-09 continue board redesign
    [Pick Place for ultrasonic_tank_monitor.csv, ultrasonic_tank_monitor.PcbDoc, ultrasonic_tank_monitor.PrjPcb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]
2023-12-21 begin html config page development
    [ultrasonic_tank_monitor.PcbDoc, ultrasonic_tank_monitor_power.SchDoc]
2024-01-11 modify schematics and change configuration
    [ultrasonic_tank_monitor.PcbDoc, ultrasonic_tank_monitor_power.SchDoc]
2024-01-12 remove old 3d file of pcb
    [ultrasonic_tank_monitor - Board.step-1 Open CASCADE STEP translator 6.8 1.1.1.step-1.STL, ultrasonic_tank_monitor - C1.step-1 0603_cap.step-1.STL, ultrasonic_t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]
2024-01-14 refactor some sections, fix major mqtt disconnect bug
    [config.h, main.cpp]
2024-01-14 roll back pcb to v1
    [Copy of ultrasonic_tank_monitor_battery_TP4056.SchDoc, Pick Place for ultrasonic_tank_monitor.csv, ultrasonic_tank_monitor.PcbDoc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]
2024-01-15 add schematics to demo
    [ultrasonic_tank_monitor.PrjPcb]
2024-04-06 set sleep time to 600s, refactor sleep/reset logic in OTA loop, add timeout for OTA 10m
    [config.h, main.cpp]
